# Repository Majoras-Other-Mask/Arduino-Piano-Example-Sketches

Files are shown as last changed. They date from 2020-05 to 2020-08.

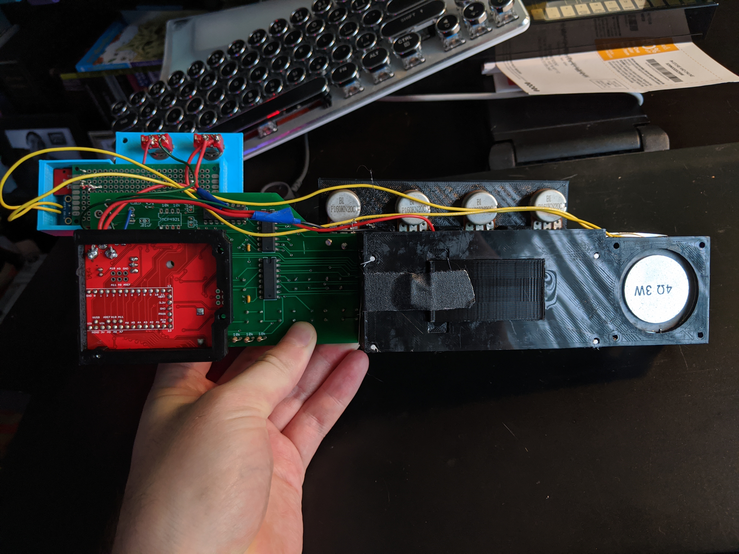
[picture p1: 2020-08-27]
Photos/IMG_20200827_090029.jpg

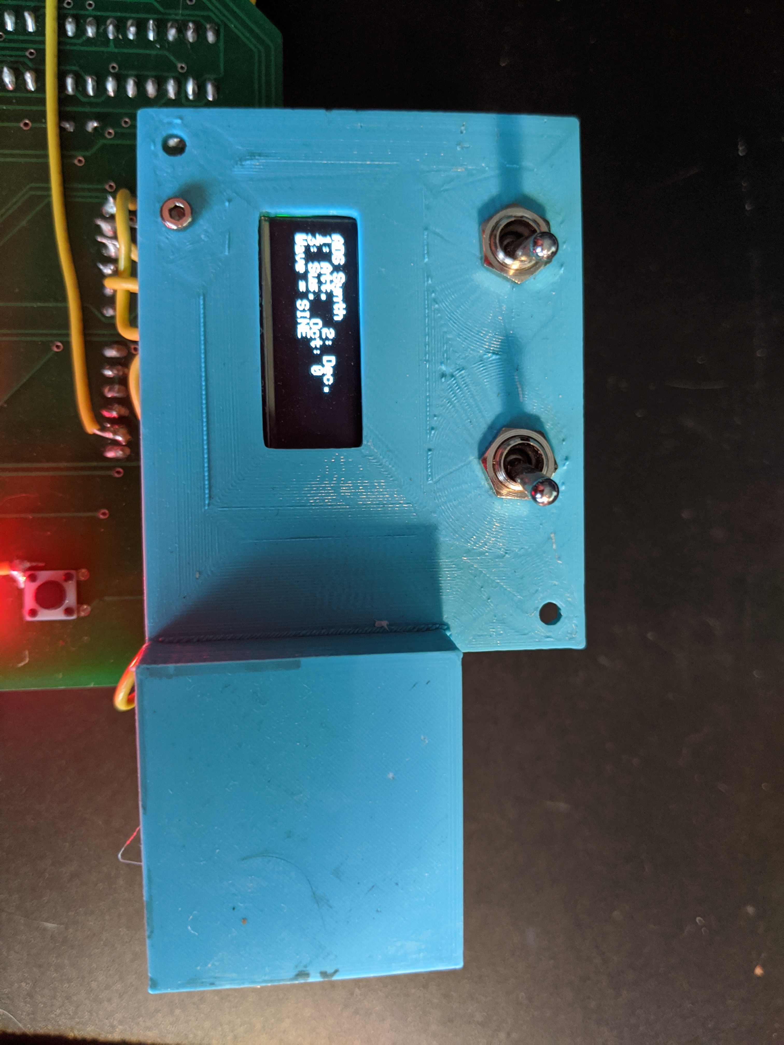
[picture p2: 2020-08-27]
Photos/IMG_20200827_090014.jpg

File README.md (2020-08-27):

DIY Pocket Piano
==============================
This started as a fork of the Critter and Guitari Arduino Pocket Piano which used to be a synth on an Arduino shield that you could buy from them. The shield is no longer made so I ordered some PCBs and all the necessary bits and pieces. Once assessmbled I started to mess with the code to add increased functionality. The Arduino Uno was not able to do everything I wanted so I have switched over to using a Teensy and SparkFun's Teensy Arduino Shield. I am currently working on designing a PCB that fits the Teensy directly. The main sketch is located in the "Teensy_Audio_Modes" folder. A major item that is missing right now is the BOM for my current build and the revisions I had to make to the PCB to get everything working correctly. 

Folders are as follows: 
1) Original CG Files: includes all the original files including PCB
2) Combined CG Files - Teensy and Arduino: Contains sketches for both Arduino and Teensy that have the simple play and octave arp sketches combined into one sketch
3) Photos: Contains photos from CG and photos of my current build
4) Solidworks Modeling: Contains Solidwork Part files and STLs for the parts I 3D printed for my current build
5) Teensy Intermediate Steps: Contains intermediate sketches I made while figuring out how to port this to Teensy. Files may or may not work
6) Teensy_Audio_Modes: The working file for using the Teensy synth
7) Teensy_Synth_PCB: The early stages of the PCB I am designing using KiCad.

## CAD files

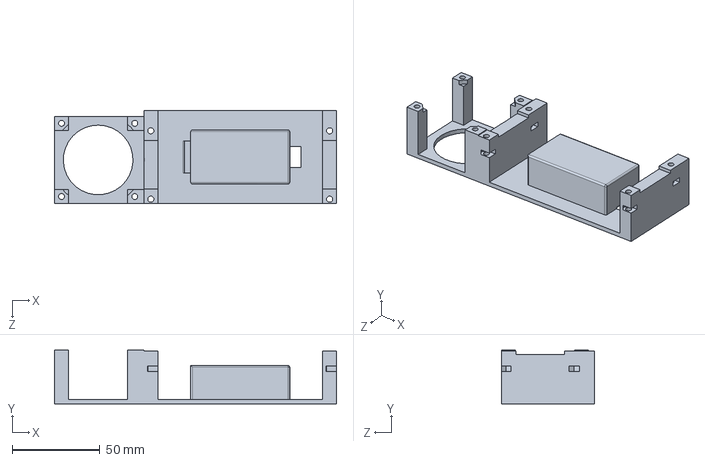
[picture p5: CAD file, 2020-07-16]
Soldiworks Modeling/Battery Holder.SLDPRT
160.4 x 30.5 x 53.0 mm

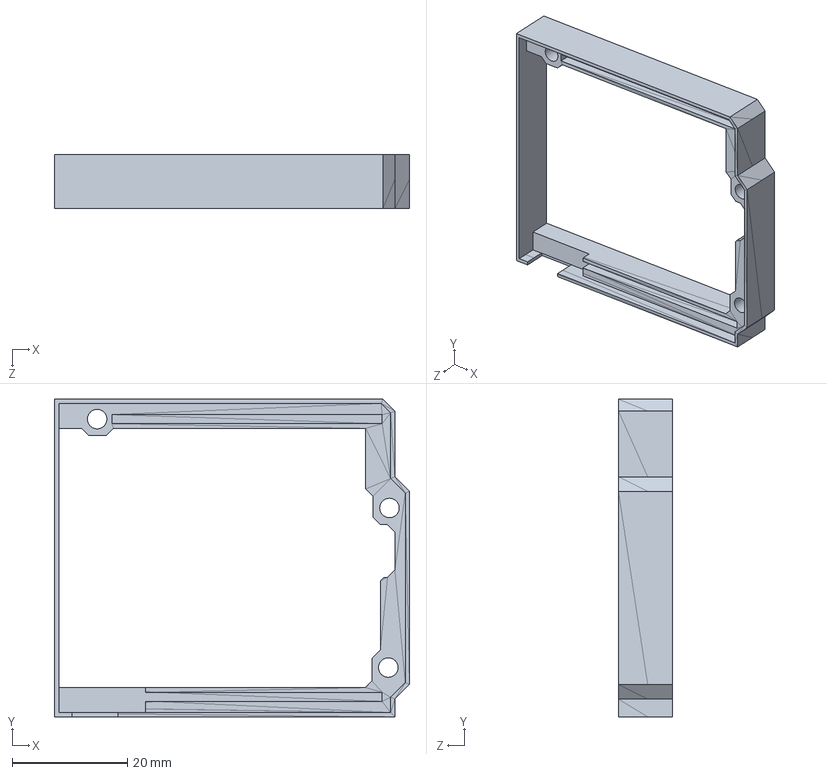
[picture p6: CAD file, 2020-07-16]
Soldiworks Modeling/Speaker_Arduino.SLDPRT
61.7 x 55.2 x 9.40 mm

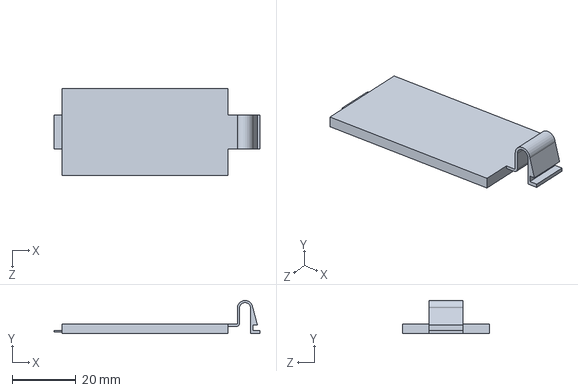
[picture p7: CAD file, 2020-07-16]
Soldiworks Modeling/BATTERY COVER.SLDPRT
64.8 x 10.4 x 27.3 mm

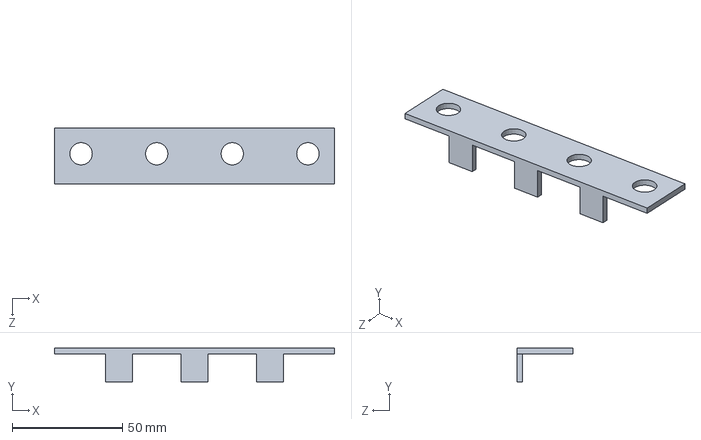
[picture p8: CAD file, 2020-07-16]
Soldiworks Modeling/PotHolder.SLDPRT
127.0 x 15.2 x 25.4 mm

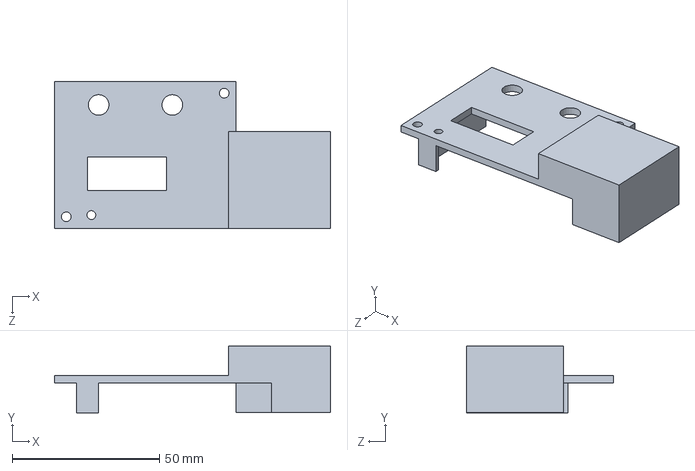
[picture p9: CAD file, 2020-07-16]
Soldiworks Modeling/FacePlate.SLDPRT
93.7 x 22.7 x 50.0 mm

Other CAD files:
Soldiworks Modeling/BATTERY COVER.STL
Soldiworks Modeling/Battery Holder.STL
Soldiworks Modeling/FacePlate.STL
Soldiworks Modeling/PotHolder.STL
Soldiworks Modeling/Speaker_Arduino.STL

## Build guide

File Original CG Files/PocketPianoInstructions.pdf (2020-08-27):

# Pocket Piano Arduino Kit

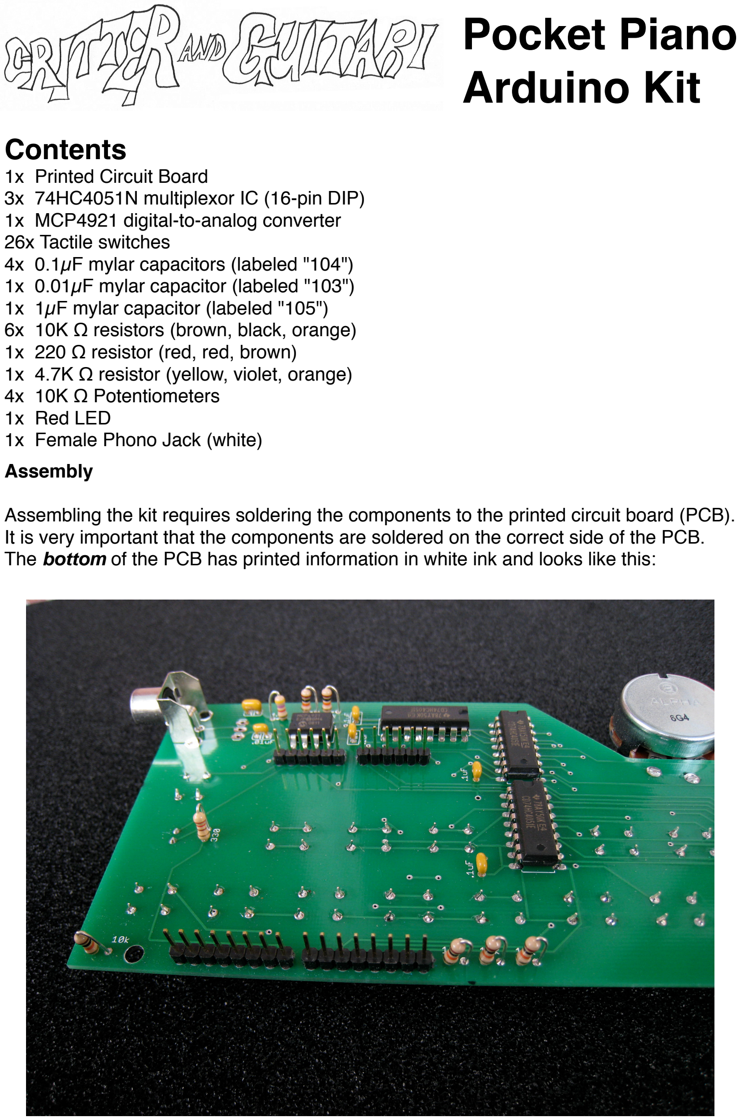
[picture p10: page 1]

## Contents

1x Printed Circuit Board
3x 74HC4051N multiplexor IC (16-pin DIP) 1x MCP4921 digital-to-analog converter 26x Tactile switches
4x 0.1µF mylar capacitors (labeled "104") 1x 0.01µF mylar capacitor (labeled "103") 1x 1µF mylar capacitor (labeled "105") 6x 10K Ω resistors (brown, black, orange) 1x 220 Ω resistor (red, red, brown)
1x 4.7K Ω resistor (yellow, violet, orange) 4x 10K Ω Potentiometers
1x Red LED
1x Female Phono Jack (white)
Assembly

Assembling the kit requires soldering the components to the printed circuit board (PCB). It is very important that the components are soldered on the correct side of the PCB. The bottom of the PCB has printed information in white ink and looks like this:

The top is the side without any printed information and looks like this:

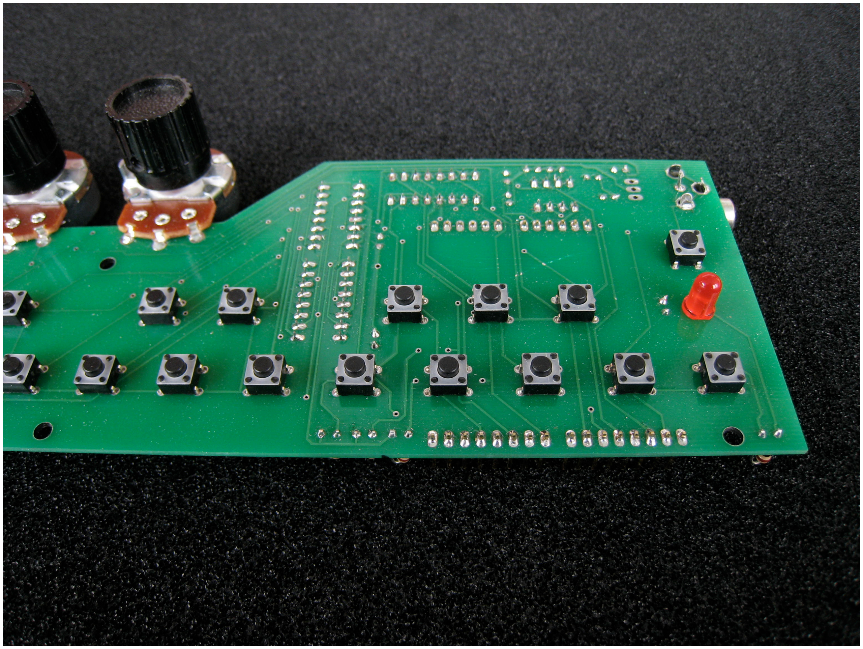
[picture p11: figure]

Components should be soldered in this order (the bottom should be soldered first.):

1. Integrated Circuits (ICs) - three multiplexors and one digital-to-analog converter. Make sure the orientation notches on the sockets line up with the notches on socket outline drawings on the circuit board. The legs of the ICs might be too wide for the sockets (as the case usually is) so gently bend them to a narrower angle.
2. Capacitors
3. Resistors The resistors are to be soldered in vertical orientation (See photo above)
4. Header Pins
5. RCA Jack

### Top

1. Tactile Switches
2. LED - The cathode of the LED (the flat part of the red plastic) faces the opposite side of the PCB as the potentiometers.
3. Potentiometers. Be sure to solder both sides of the through holes for extra strength as shown below:

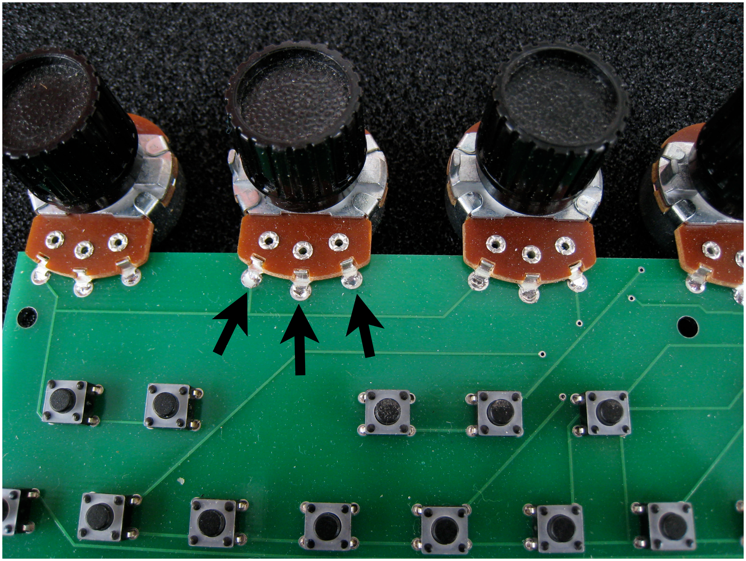
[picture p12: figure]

Power

The circuit requires a 9 VDC center positive power adapter if you want to use it away from your computer. Be sure to switch the power header on your Arduino to 'external.'

© Critter and Guitari 2008. All Rights Reserved.

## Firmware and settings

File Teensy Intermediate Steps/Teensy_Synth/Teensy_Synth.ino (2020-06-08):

/*********************************************
Current "Engines": 
1) Simple Play (basic keyboard)
    Knob 1 = NA
    Knob 2 = NA
2) Octave Arpeggiator 
    Knob 1 = Delay
    Knob 2 = NA

Waveforms (change with key 23 + 25): 
1)?
2) Sine
3) Triangle

Pitch Shift: 
1) ON (key 22 + 25) = Knob 3 to control
2) OFF (key 24 + 25)

Volume is on Knob 4

Screen displays (can be run without screen): 
  Mode
  Pitch (on/off)
  Knob function
  Waveform

 *********************************************/
//Create interval timer object
IntervalTimer myTimer; 

 //*********************************************/
//Screen Setup Here
#include <SPI.h>
#include <Wire.h>
#include <Adafruit_GFX.h>
#include <Adafruit_SSD1306.h>

#define SCREEN_WIDTH 128 // OLED display width, in pixels
#define SCREEN_HEIGHT 32 // OLED display height, in pixels

// Declaration for an SSD1306 display connected to I2C (SDA, SCL pins)
#define OLED_RESET     A3 // Reset pin # (or -1 if sharing Arduino reset pin)
Adafruit_SSD1306 display(SCREEN_WIDTH, SCREEN_HEIGHT, &Wire, OLED_RESET);

//***************************************************
//Variable and Hardware Pin Setup Here
//IDK why I need this but it currently is not working else a digital output 
//pin is connected to amp Vin
//#define RAND 0

//Slave Select Pin on Chip
#define slaveSelectPin 9 

//Setup function keys
#define KEY_25 10 //function button is key 25 connected to pin 10
int pin25;
int old25; 
int secondFunc; 
int octaveShift;
int octaveDisplay;  

//storage variables
int pitchMode; 
int mode;
String modeString[] = {"Simple Play", "Octave Arp", "FM"};  
String pitchString[] = {"Pitch = OFF", "Pitch = ON "}; 
String knob1String[] = {"1 = NA", "1 = Delay", "1 = Harm." }; 
String knob2String[] = {"2 = NA", "2 = NA", "2 = Depth"};
String waveString[] = {"Wave = Saw", "Wave = Sine", "Wave = Triangle", "Wave = Square", "Wave = Pulse", "Wave = Fuzz",
                      "Wave = Digital", "Wave = Tan"}; 

//Setup LED
#define PP_LED 8   // LED on pocket piano

//Setup counters
int i;
int j;
int k; 
int n; 
 

//***************************************************
//Audio Stuff here
// define pins to read buttons
#define MUX_SEL_A 4
#define MUX_SEL_B 3
#define MUX_SEL_C 2
#define MUX_OUT_0 7
#define MUX_OUT_1 6
#define MUX_OUT_2 5

//This has low C set to F#6
// here are some 12 tone equal temperament pitches.  We will scale these with a 'tune' knob
//Set so that low C is set to C6
uint32_t miditof[] = {
  0, //need this 0 in order to have a silen note when not playing
  4188,
  4436,
  4700,
  4980,
  5276,
  5588,
  5920,
  6272,
  6645,
  7040,
  7459,
  7902,
  8372,
  8870,
  9397,
  9956,
  10548,
  11175,
  11840,
  12544,
  13290,
  14080,
  14918,
  15804
};

//this will be a reference for octave shifting
uint32_t miditofBase[] = {
  0, //need this 0 in order to have a silen note when not playing
  4188,
  4436,
  4700,
  4980,
  5276,
  5588,
  5920,
  6272,
  6645,
  7040,
  7459,
  7902,
  8372, 
  8870,
  9397,
  9956,
  10548,
  11175,
  11840,
  12544,
  13290,
  14080,
  14918,
  15804,
};
// this 32 bit number holds the states of the 24 buttons, 1 bit per button
uint32_t buttons = 0xFFFFFFFF;

// holds frequency value used for oscillator in phase steps
// this is an integer proportial to Hertz in the following way:
// frequency  = (FrequencyInHertz * 65536) / SampleRate, here sample rate is 15625
//uint32_t frequency = 0;

// this is the wave form of the oscillators 
uint8_t waveForm;

// tuning knob 
int pitchScale;

//knob 1
int knob1; 

//knob 2
int knob2; 

//gain
uint8_t gn = 0xff; 

// holds frequency value used for oscillator in phase steps
// this is an integer proportial to Hertz in the following way:
// frequency  = (FrequencyInHertz * 65536) / SampleRate, here sample rate is 15625
uint32_t freq[] = {0, 0, 0, 0}; //setting for 4 note poly synth

// voices (up to keys held down)
uint8_t key[] = {0, 0, 0, 0}; //setting for 4 note poly synth

// octave multiplier
uint8_t octave = 0; 

void setup() {
  //******************************************************
  //Timer Setup
  myTimer.priority(0); 
  myTimer.begin(sendNote, 64); 
  
  //******************************************************
  //SPI Setup
  //pinMode(RAND, OUTPUT);
  pinMode(slaveSelectPin, INPUT); 
  SPI.usingInterrupt(myTimer);  
  SPI.begin();  

  //******************************************************
  // configure pins for multiplexer
  pinMode(MUX_SEL_A, OUTPUT);  // these are the select pins
  pinMode(MUX_SEL_B, OUTPUT);
  pinMode(MUX_SEL_C, OUTPUT);


  pinMode(MUX_OUT_0, INPUT);
  pinMode(MUX_OUT_1, INPUT);
  pinMode(MUX_OUT_2, INPUT);

  digitalWrite(MUX_SEL_A, 1);   // multiplexer outputs, 8 each
  digitalWrite(MUX_SEL_B, 1);
  digitalWrite(MUX_SEL_C, 1);

  //******************************************************
  //Misc. Setup happens here
  pinMode(PP_LED, OUTPUT); //setup LED
  pinMode(KEY_25, OUTPUT); 
  //pinMode(KEY_25, INPUT); //pin works as an input but if I uncomment this line everything breaks ¯\_(ツ)_/¯ 
  i = 0; 
  j = 0; 
  pin25 = 0; 
  mode = 0; 
  pitchMode = 0; 
  octaveShift = 2; 
  octaveDisplay = 0; 
  waveForm = 1; //starting waveform 

  //flash led to let us know it is turning on
  digitalWrite(PP_LED, 1);
  delay(100);
  digitalWrite(PP_LED, 0);
  delay(100);
  digitalWrite(PP_LED, 1);
  delay(100);
  digitalWrite(PP_LED, 0);
  delay(100);
  digitalWrite(PP_LED, 1);

  //Turning on serial for debugging
  Serial.begin(9600);

  //******************************************************
  //Screen Setup happens here

  //Uncomment the below if you want to check if the screen is working, not necessary if not using screen
  //  // SSD1306_SWITCHCAPVCC = generate display voltage from 3.3V internally
  if (!display.begin(SSD1306_SWITCHCAPVCC, 0x3C)) { // Address 0x3C for 128x32
    Serial.println(F("SSD1306 allocation failed"));
    for (;;) {
      // Don't proceed, loop forever if screen not found
      digitalWrite(PP_LED, 1);
      delay(100);
      digitalWrite(PP_LED, 0);
      delay(100);
    }
  }
  // Show initial display buffer contents on the screen --
  // the library initializes this with an Adafruit splash screen.
  display.display();
  delay(2000); // Pause for 2 seconds
  
  //get starting screen
  screenUpdate(); 

  //******************************************************
  //We can print a serial message to say hi as well (useful for debugging)
  Serial.println("Hello from your synthesizer");

  //Turn LED on to let us know we are ready to start
  digitalWrite(PP_LED, 0);
  
  
  analogWriteResolution(12); 
}


void loop(void)
{
  //knob 1 and 2 are mode dependent
  knob1 = analogRead(A0); 
  knob2 = analogRead(A1); 

  //pitch knob can be turned on and off
  if (pitchMode == 1) { 
    //knob 3 is for the pitch
    pitchScale = analogRead(2);
  } else { 
    pitchScale = 128; //this lets us scale to C6 when not tuning using pitch knob
  }
  
  //get the state of the buttons
  getButtons();

  //Get up to 4 keys
  k = 0;  
  key[0] = key[1] = key[2] = key[3] = 0;
  for (i = 0; i < 25; i++){             // read through buttons
    if ( !((buttons >> i) & 1) ){
      key[k] = i + 1;
      //Serial.println(key[0]);  
      k++;
      k &= 0x3;
    }
  }  
    
  //secondFunc key is alwasys the lowest note played
  secondFunc = key[0]; 
  //call function key function
  key25Func(); 
  
  //apply octave shift
  if (octaveDisplay > 0) { 
    for (n = 0; n < 4; n++) { 
      miditof[key[n]] = miditofBase[key[n]] << octaveDisplay;
    }
  } else if (octaveDisplay < 0) { 
    for (n = 0; n < 4; n++) { 
      miditof[key[n]] = miditofBase[key[n]] >> abs(octaveDisplay);
    }
  } else { 
    for (n = 0; n < 4; n++) { 
      miditof[key[n]] = miditofBase[key[n]];
    }
  } 
  
  //actually playing the notes! 
  if (mode == 1) { //octave arp mode    
    // do octave increase
    octave++;
    // only from 0 - 3
    octave &= 3;
    for (n = 0; n < 4; n++) { 
      freq[n] =  ((((miditof[key[n]]) * (pitchScale)) >> 9)>> octave);
    }
    delay(knob1 >> 2);   // sweep speed
  } else if (mode == 2) { //simple FM synth
    for (n = 0; n < 4; n++) {  
      freq[n] =  ((miditof[key[n]]) * (pitchScale)) >> 12;
    }
    delay(10); 
  } else { //simple play mode, only pitch is affected
        for (n = 0; n < 4; n++) { 
      freq[n] =  ((miditof[key[n]]) * (pitchScale)) >> 9;
    }
    delay(10);   // wait 10 ms 
  }
}

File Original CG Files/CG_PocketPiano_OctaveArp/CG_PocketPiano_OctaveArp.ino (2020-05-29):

/*********************************************
 * Plays Tones on Arduino Pocket Piano
 * Author: Owen Osborn, Copyright: GPL 
 * 
 *  This uses Direct Digital Synthesis (DDS)  for tone generation
 * 
 *   maps 25 of the buttons to tones
 *
 * 5 October 2007
 *
 * FOR MCP4921 DAC
 *
 * Chip type           : ATMEGA168
 * Clock frequency     : 16MHz
 *********************************************/

// define pins to read buttons
#define MUX_SEL_A 4
#define MUX_SEL_B 3
#define MUX_SEL_C 2
#define MUX_OUT_0 7
#define MUX_OUT_1 6
#define MUX_OUT_2 5

// here are some 12 tone equal temperament pitches.  We will scale these with a 'tune' knob
uint32_t miditof[] = {
  0,
  5920,
  6272,
  6645,
  7040,
  7459,
  7902,
  8372,
  8870,
  9397,
  9956,
  10548,
  11175,
  11840,
  12544,
  13290,
  14080,
  14918,
  15804,
  16744,
  17740,
  18794,
  19912,
  21096,
  22350,
  23680,
  25088
};


#define PP_LED 8   // LED on pocket piano

// this 32 bit number holds the states of the 24 buttons, 1 bit per button
uint32_t buttons = 0xFFFFFFFF;

// holds frequency value used for oscillator in phase steps
// this is an integer proportial to Hertz in the following way:
// frequency  = (FrequencyInHertz * 65536) / SampleRate, here sample rate is 15625
uint32_t frequency[] = {
  1400, 0, 0, 0};

// this is the wave form of the oscillators 1 = sine wave, 2 = triangle, 0 = sawtooth
uint8_t waveForm = 2;

// tuning knob 
int pitchScale;

// voices (up to keys held down)
uint8_t key[] = {0, 0, 0, 0};

// octave multiplier
uint8_t octave = 0;

void setup(){
  //Timer2 setup  This is the audio rate timer, fires an interrupt at 15625 Hz sampling rate
  TIMSK2 = 1<<OCIE2A;  // interrupt enable audio timer
  OCR2A = 127;
  TCCR2A = 2;               // CTC mode, counts up to 127 then resets
  TCCR2B = 0<<CS22 | 1<<CS21 | 0<<CS20;   // different for atmega8 (no 'B' i think)
  SPCR = 0x50;   // set up SPI port
  SPSR = 0x01;
  DDRB |= 0x2E;       // PB output for DAC CS, and SPI port
  PORTB |= (1<<1);   // CS high
  
  sei();          // enable interrupts

  // configure pins for multiplexer
  pinMode(MUX_SEL_A, OUTPUT);  // these are the select pins
  pinMode(MUX_SEL_B, OUTPUT);
  pinMode(MUX_SEL_C, OUTPUT);
  
  
  pinMode(MUX_OUT_0, INPUT);
  pinMode(MUX_OUT_1, INPUT);
  pinMode(MUX_OUT_2, INPUT);

  digitalWrite(MUX_SEL_A, 1);   // multiplexer outputs, 8 each
  digitalWrite(MUX_SEL_B, 1);
  digitalWrite(MUX_SEL_C, 1);

  //flash led
  pinMode(PP_LED, OUTPUT);
  digitalWrite(PP_LED, 1);
  delay(100);
  digitalWrite(PP_LED, 0);
  delay(100);
  digitalWrite(PP_LED, 1);
  delay(100);
  digitalWrite(PP_LED, 0);

  Serial.begin(9600);
  Serial.println("hello");
  Serial.println("welcome to synthesizer");

}


void loop(void)
{

  int i, j;
  
  pitchScale = analogRead(2);

  getButtons();  
  
  j = 0;  
  key[0] = key[1] = key[2] = key[3] = 0;
  for (i = 0; i < 25; i++){             // read through buttons
    if ( !((buttons >> i) & 1) ){
      key[j] = i + 1;
      j++;
      j &= 0x3;
    }
  }
  
  // do octave increase
  octave++;
  
  // only from 0 - 3
  octave &= 3;

  frequency[0] = ((((miditof[key[0]]) * (pitchScale)) >> 9)>> octave);  // scale frequency by tuning knob and octave
  frequency[1] = ((((miditof[key[1]]) * (pitchScale)) >> 9)>> octave);
  frequency[2] = ((((miditof[key[2]]) * (pitchScale)) >> 9)>> octave);
  frequency[3] = ((((miditof[key[3]]) * (pitchScale)) >> 9)>> octave);
  
  
  delay(analogRead(0) >> 2);   // sweep speed
}

// this funcion reads the buttons and stores their states in the global 'buttons' variable
void getButtons(void){
  int i;
  buttons = 0;
  for (i = 0; i < 8; i++){
    digitalWrite(MUX_SEL_A, i & 1);
    digitalWrite(MUX_SEL_B, (i >> 1) & 1);
    digitalWrite(MUX_SEL_C, (i >> 2) & 1);
    buttons |= digitalRead(MUX_OUT_2) << i;  
  }
  buttons <<= 8;
  for (i = 0; i < 8; i++){
    digitalWrite(MUX_SEL_A, i & 1);
    digitalWrite(MUX_SEL_B, (i >> 1) & 1);
    digitalWrite(MUX_SEL_C, (i >> 2) & 1);
    buttons |= digitalRead(MUX_OUT_1) << i;
  }
  buttons <<= 8;
  for (i = 0; i < 8; i++){
    digitalWrite(MUX_SEL_A, i & 1);
    digitalWrite(MUX_SEL_B, (i >> 1) & 1);
    digitalWrite(MUX_SEL_C, (i >> 2) & 1);
    buttons |= digitalRead(MUX_OUT_0) << i;   
  }
  buttons |= 0x1000000;  // for the 25th button

  // uncomment these two lines to use the 25th button, if the board is modified so button connects to PC 3
//  if (!(PINC & 0x8))      
//    buttons &= ~0x1000000;  
}

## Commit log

2020-05-20 First Attempt at Creating an ARM version of code
    Attempting to port SimplePlay to Teensy
2020-05-31 Got Teensy version working!
2020-05-31 Formated Teensy Sketch
2020-06-08 Updated teensy code
2020-06-09 Matches CG Pocket Piano
    Teensy Audio Modes now matches the CG Pocket Piano as far as I am going to take it. Key differences: mono FM synth isn't mono (4 notes). FM synth has freq modulation instead of harmonicity, no glide mode (easy to implement with tonesweep in audio library but not something I want to use right now). No hold function (yet).
    Next steps. Add hold function (need to solder reset button to D0), look into adding Pocket Operator mode (have one DAC send click track to correct part of headphone jack. Could have 1 of the knobs control tempo and have that displayed on screen).
    [funcs.ino]
2020-07-16 Working Rev
    [BATTERY COVER.SLDPRT, BATTERY COVER.STL, Battery Holder.SLDPRT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]
2020-08-27 Organized files a bit
    [BATTERY COVER.SLDPRT, BATTERY COVER.STL, Battery Holder.SLDPRT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]
